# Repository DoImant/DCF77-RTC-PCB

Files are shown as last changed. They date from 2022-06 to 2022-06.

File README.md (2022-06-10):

# Circuit board for a DCF77 radio clock.

This project is a circuit board for the components of a DCF77 radio clock.
The components (display, RTC module and DFC77 receiver can be plugged in directly or connected by cable. 
The buttons for controlling the date display and the backlight must be connected by cable.

## The PCB

PCB



PCB Front

PCB Back

## Software

The software and a breadboard setup are presented here: https://github.com/DoImant/Arduino-DCF77-RTC

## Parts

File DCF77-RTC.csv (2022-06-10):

Source: | C:\Users\Kai\HiDrive\users\kai-r\Elektronik\KiCad\v6\1Projects\DCF77-RTC\DCF77-RTC.kicad_sch
Date: | 09.06.2022 16:34:54
Tool: | Eeschema (6.0.5)
Generator: | D:\Programme\KiCad6\bin\scripting\plugins/bom_csv_grouped_by_value_with_fp.py
Component Count: | 30
Ref | Qnty | Value | Cmp name | Footprint | Description | Vendor
C1, C2, | 2 | 1u | C_Small | Capacitor_SMD:C_1206_3216Metric_Pad1.33x1.80mm_HandSolder | Unpolarized capacitor, small symbol
C3, C4, | 2 | 100n | C_Small | Capacitor_SMD:C_0805_2012Metric_Pad1.18x1.45mm_HandSolder | Unpolarized capacitor, small symbol
D1, | 1 | LED | LED | LED_SMD:LED_1206_3216Metric_Pad1.42x1.75mm_HandSolder | Light emitting diode
H1, H2, H3, H4, | 4 | MountingHole | MountingHole | MountingHole:MountingHole_3mm | Mounting Hole without connection
J1, | 1 | Conn_01x02_Male | Conn_01x02_Male | Connector_JST:JST_XH_B2B-XH-A_1x02_P2.50mm_Vertical | Generic connector, single row, 01x02, script generated (kicad-library-utils/schlib/autogen/connector/)
J2, | 1 | ISP | Conn_02x03_Odd_Even | Connector_IDC:IDC-Header_2x03_P2.54mm_Vertical | Generic connector, double row, 02x03, odd/even pin numbering scheme (row 1 odd numbers, row 2 even numbers), script generated (kicad-library-utils/schlib/autogen/connector/)
J3, | 1 | LCD_Carrier_Board | Conn_01x10 | Connector_PinSocket_2.54mm:PinSocket_1x10_P2.54mm_Vertical | Generic connector, single row, 01x10, script generated (kicad-library-utils/schlib/autogen/connector/)
J4, J6, J8, | 3 | Conn_01x02 | Conn_01x02 | Connector_PinHeader_2.54mm:PinHeader_1x02_P2.54mm_Vertical | Generic connector, single row, 01x02, script generated (kicad-library-utils/schlib/autogen/connector/)
J5, | 1 | DS3231 | Conn_01x06 | Connector_PinSocket_2.54mm:PinSocket_1x06_P2.54mm_Vertical | Generic connector, single row, 01x06, script generated (kicad-library-utils/schlib/autogen/connector/)
J7, | 1 | DCF77-Receiver | Conn_01x03 | Connector_PinSocket_2.54mm:PinSocket_1x03_P2.54mm_Vertical | Generic connector, single row, 01x03, script generated (kicad-library-utils/schlib/autogen/connector/)
Q1, | 1 | BC847 | BC847 | Package_TO_SOT_SMD:SOT-23 | 0.1A Ic, 45V Vce, NPN Transistor, SOT-23
Q2, Q3, | 2 | IRLML6402 | IRLML6402 | Package_TO_SOT_SMD:SOT-23 | -3.7A Id, -20V Vds, 65mOhm Rds, P-Channel HEXFET Power MOSFET, SOT-23
R1, | 1 | 22K | R | Resistor_SMD:R_1206_3216Metric_Pad1.30x1.75mm_HandSolder | Resistor
R2, R3, | 2 | 1k | R | Resistor_SMD:R_1206_3216Metric_Pad1.30x1.75mm_HandSolder | Resistor
R4, | 1 | 470R | R | Resistor_SMD:R_1206_3216Metric_Pad1.30x1.75mm_HandSolder | Resistor
R5, R7, | 2 | 8k2 | R | Resistor_SMD:R_1206_3216Metric_Pad1.30x1.75mm_HandSolder | Resistor
R6, | 1 | 39k | R | Resistor_SMD:R_1206_3216Metric_Pad1.30x1.75mm_HandSolder | Resistor
R8, | 1 | 22k | R | Resistor_SMD:R_1206_3216Metric_Pad1.30x1.75mm_HandSolder | Resistor
U1, | 1 | MCP1700-3002E_SOT23 | MCP1700-3002E_SOT23 | Package_TO_SOT_SMD:SOT-23 | 250mA Low Quiscent Current LDO, 3.0V output, SOT-23
U2, | 1 | ATtiny88-P | ATtiny88-P | Package_DIP:DIP-28_W7.62mm_Socket_LongPads | 12MHz, 8kB Flash, 512B SRAM, 64B EEPROM, DIP-28

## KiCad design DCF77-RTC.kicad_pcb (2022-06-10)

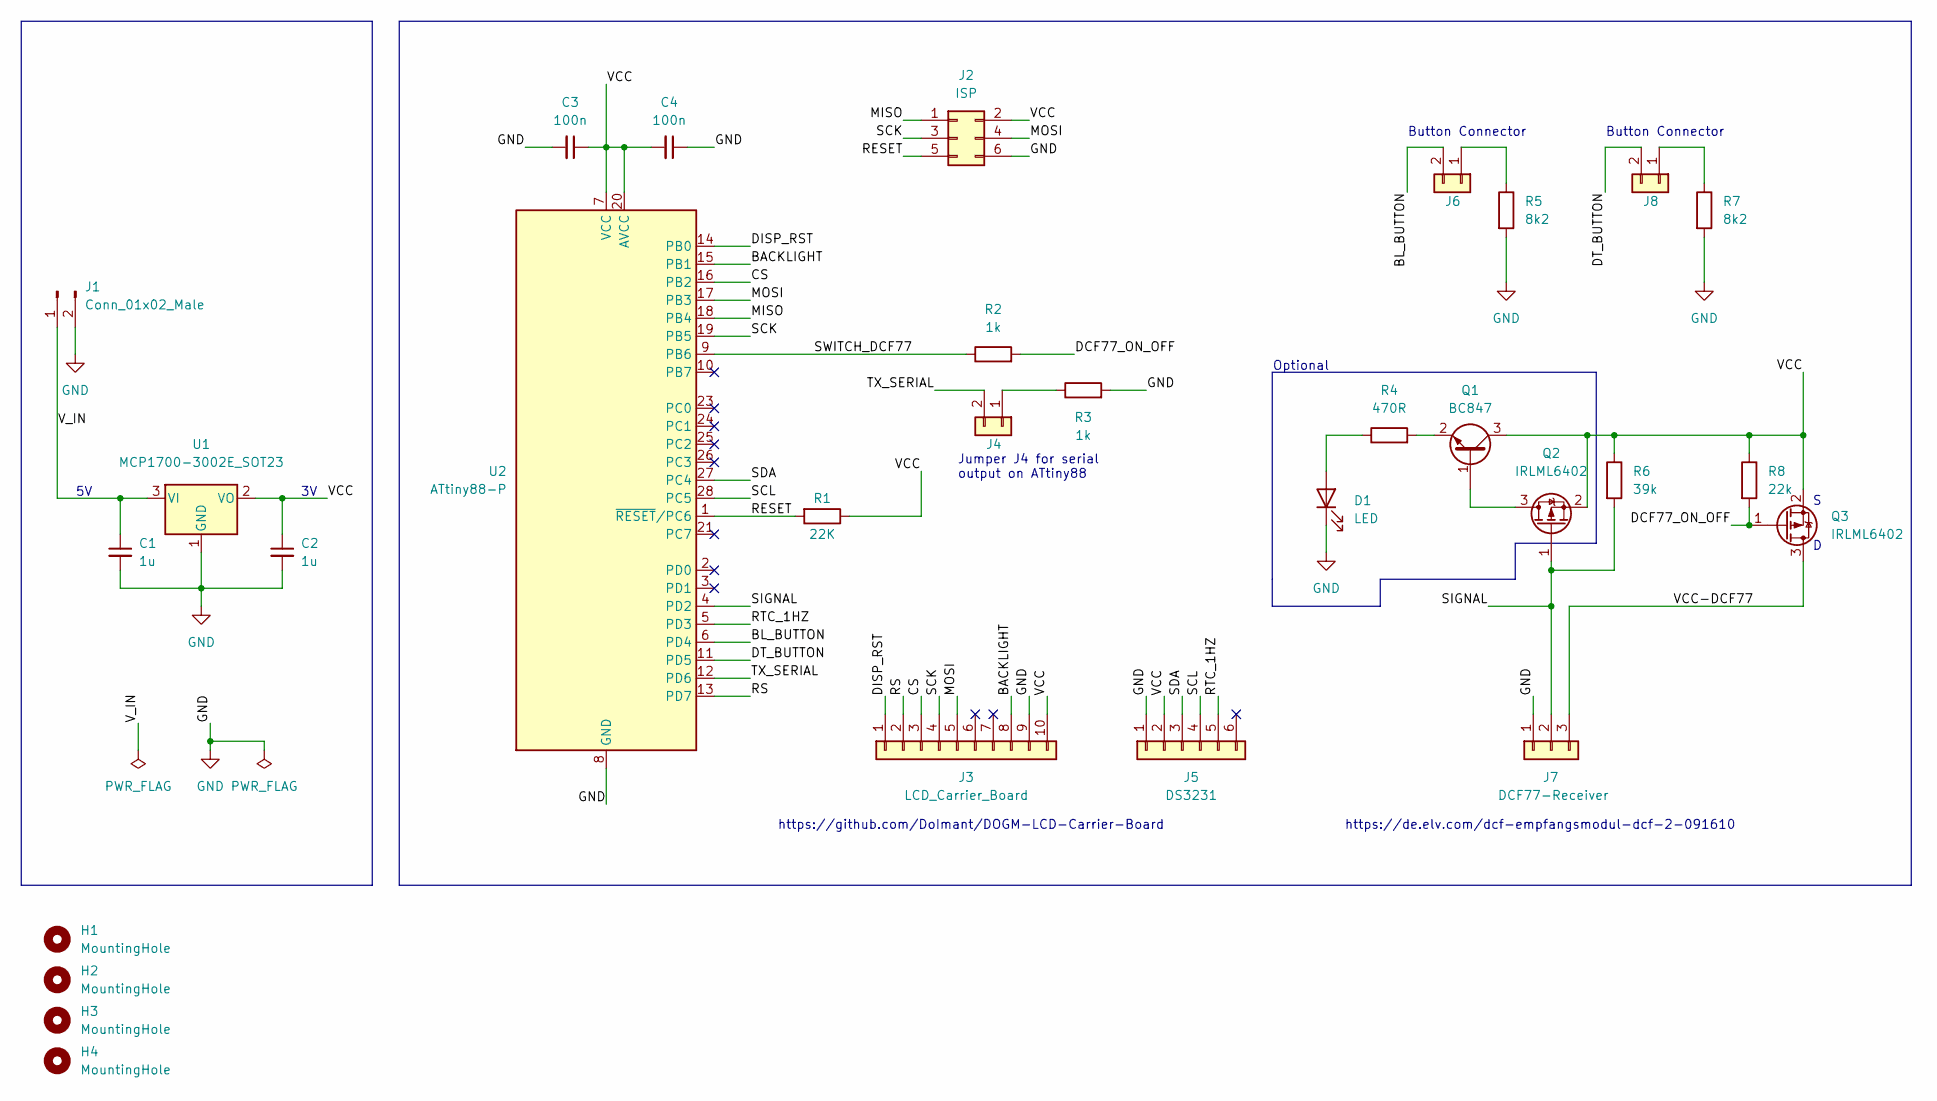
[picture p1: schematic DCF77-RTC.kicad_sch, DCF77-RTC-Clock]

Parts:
C1, C2: 1u; C_1206_3216Metric_Pad1.33x1.80mm_HandSolder
C3, C4: 100n; C_0805_2012Metric_Pad1.18x1.45mm_HandSolder
D1: LED; LED_1206_3216Metric_Pad1.42x1.75mm_HandSolder
H1, H2, H3, H4: MountingHole; MountingHole_3mm
J1: Conn_01x02_Male; JST_XH_B2B-XH-A_1x02_P2.50mm_Vertical
J2: ISP; IDC-Header_2x03_P2.54mm_Vertical
J3: LCD_Carrier_Board; PinSocket_1x10_P2.54mm_Vertical
J4, J6, J8: Conn_01x02; PinHeader_1x02_P2.54mm_Vertical
J5: DS3231; PinSocket_1x06_P2.54mm_Vertical
J7: DCF77-Receiver; PinSocket_1x03_P2.54mm_Vertical
Q1: BC847; SOT-23
Q2, Q3: IRLML6402; SOT-23
R1: 22K; R_1206_3216Metric_Pad1.30x1.75mm_HandSolder
R2, R3: 1k; R_1206_3216Metric_Pad1.30x1.75mm_HandSolder
R4: 470R; R_1206_3216Metric_Pad1.30x1.75mm_HandSolder
R5, R7: 8k2; R_1206_3216Metric_Pad1.30x1.75mm_HandSolder
R6: 39k; R_1206_3216Metric_Pad1.30x1.75mm_HandSolder
R8: 22k; R_1206_3216Metric_Pad1.30x1.75mm_HandSolder
U1: MCP1700-3002E_SOT23; SOT-23
U2: ATtiny88-P; DIP-28_W7.62mm_Socket_LongPads

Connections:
/BACKLIGHT: J3.8, U2.15 (PB1)
/BL_BUTTON: J6.2, U2.6 (PD4)
/CS: J3.3, U2.16 (PB2)
/DCF77_ON_OFF: Q3.1 (G), R2.2, R8.2
/DISP_RST: J3.1, U2.14 (PB0)
/DT_BUTTON: J8.2, U2.11 (PD5)
/MISO: J2.1, U2.18 (PB4)
/MOSI: J2.4, J3.5, U2.17 (PB3)
/RESET: J2.5, R1.2, U2.1 (~RESET/PC6)
/RS: J3.2, U2.13 (PD7)
/RTC_1HZ: J5.5, U2.5 (PD3)
/SCK: J2.3, J3.4, U2.19 (PB5)
/SCL: J5.4, U2.28 (PC5)
/SDA: J5.3, U2.27 (PC4)
/SIGNAL: J7.2, Q2.1 (G), R6.2, U2.4 (PD2)
/SWITCH_DCF77: R2.1, U2.9 (PB6)
/TX_SERIAL: J4.2, U2.12 (PD6)
/VCC: C2.1, C3.1, C4.2, J2.2, J3.10, J5.2, Q1.3 (C), Q2.2 (S), Q3.2 (S), R1.1, R6.1, R8.1, U1.2 (VO), U2.7 (VCC), U2.20 (AVCC)
/VCC-DCF77: J7.3, Q3.3 (D)
/V_IN: C1.1, J1.1, U1.3 (VI)
GND: C1.2, C2.2, C3.2, C4.1, D1.1 (K), J1.2, J2.6, J3.9, J5.1, J7.1, R3.2, R5.2, R7.2, U1.1 (GND), U2.8 (GND), U2.22 (GND)
unnamed: D1.2 (A), R4.1
unnamed: J4.1, R3.1
unnamed: J6.1, R5.1
unnamed: J8.1, R7.1
unnamed: Q1.1 (B), Q2.3 (D)
unnamed: Q1.2 (E), R4.2

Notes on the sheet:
Button Connector
Optional
https://github.com/DoImant/DOGM-LCD-Carrier-Board
Jumper J4 for serial output on ATtiny88
https://de.elv.com/dcf-empfangsmodul-dcf-2-091610

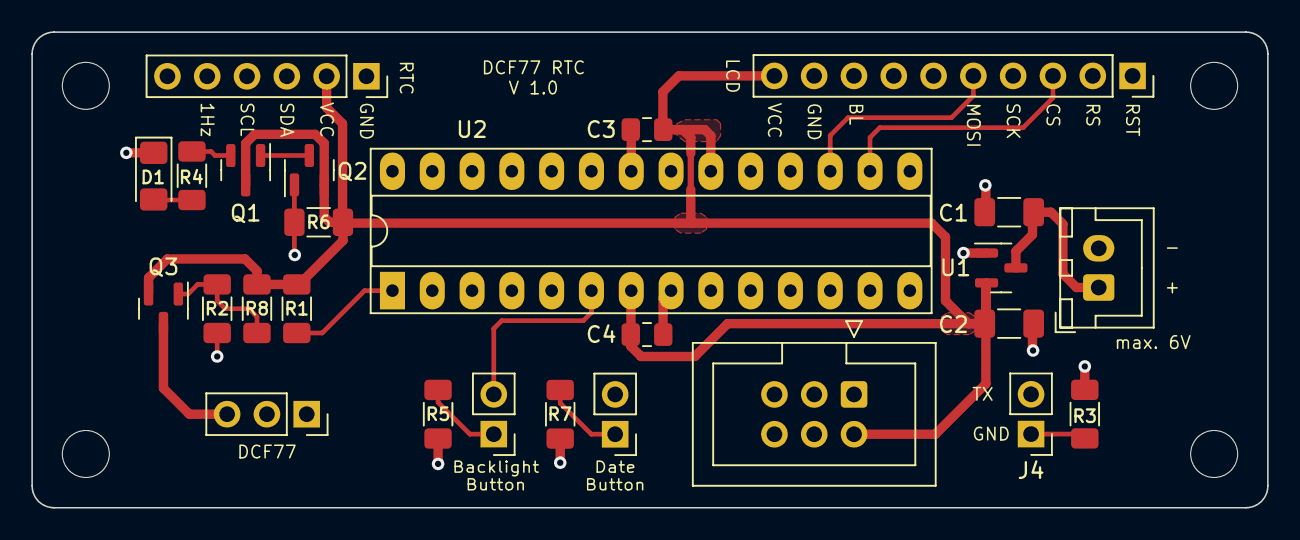
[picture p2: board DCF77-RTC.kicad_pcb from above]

Board: 4 copper layers, 78.9 x 30.4 mm, 30 parts (0 on the bottom side), 27 nets.
